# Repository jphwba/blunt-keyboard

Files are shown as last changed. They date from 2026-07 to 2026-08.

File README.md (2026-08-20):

# Blunt-Keyboard

This keyboard is a 75% keyboard which has a magnetically attatchable numpad to it. It uses a raspberry pi pico rp2040 as the microcontroller for the main keyboard while using a xiao seeed studio rp2040 as the microcontroller for the numpad. This would connect via two usb C cables into my pc. I made this because I really need a new keyboard since my current one cant even play games anymore due to some weird bug in the pcb where it just randomly spams keys, plus I've had it for almost 10 years.

## Assembly
On the main part of the keyboard, the pcb is mounted using five mounting holes on the pcb and five standoffs on the base where M2 heatset inserts will sit. On top of these standoffs will go the PCB where it will be screwed into the base. Then the top goes ontop of the pcb/base walls. This is connected via screws going from the bottom to the top
The numpad however is screwed in with the threads in the 3d print. This was not a great design choice at the time as I wasn't as experienced with how 3d printers work but I will take the gamble and if it doesn't work I am able to use tape. HOWEVER the pcb is screwed into the base using the same heatset inserts so the pcb will be secured. The key plate is attatched to the top cover with a joint (i forgot the name).
For the magnetic attatchements, two 7mm magnets go in two the 7mm wide holes on BOTH the numpad and the main keyboard and is attatched to each part with some basic super glue. With this the two devices can seamlessly attatch and detach. The two components also have seperate microcontrollers, meaning two different usb connections into my pc. I chose this over having the numpad atatch into the main keyboard for first simple firmware and schematic design but also because it means I have a portable numpad.

### Numpad Render
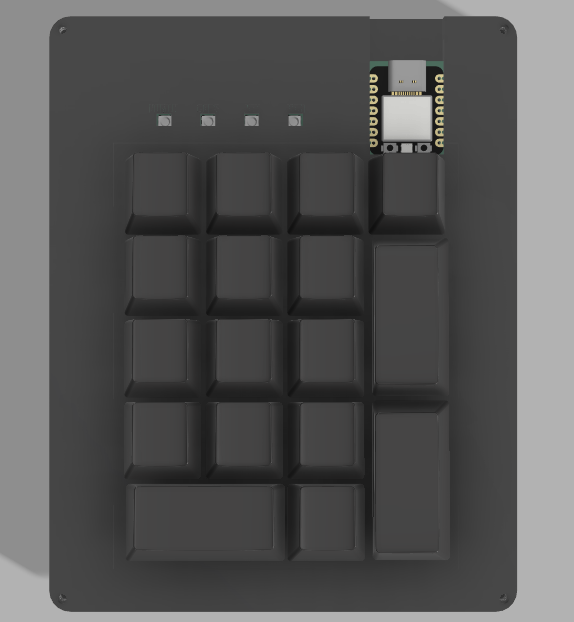
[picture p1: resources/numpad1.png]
NumPad1

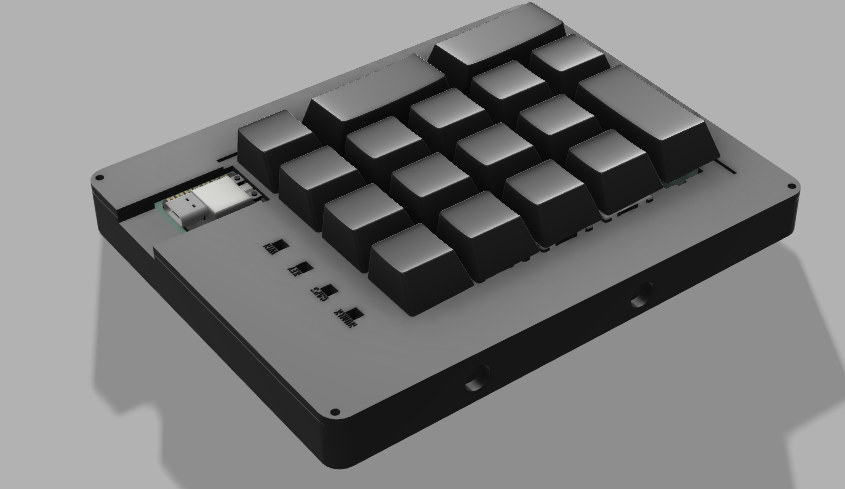
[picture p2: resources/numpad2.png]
Numpad2


### Main Keyboard Render
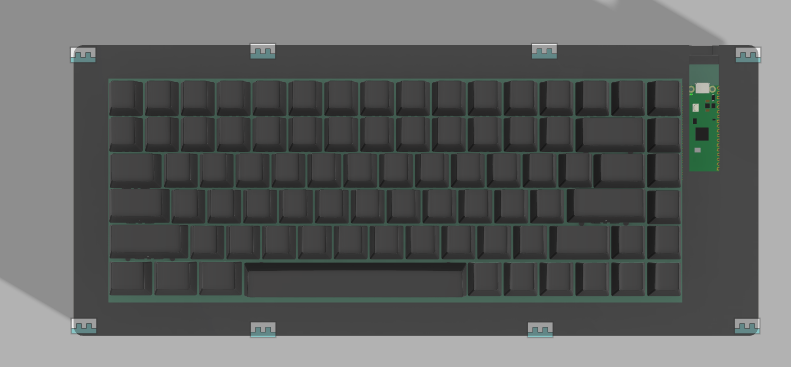
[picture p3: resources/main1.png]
Main1

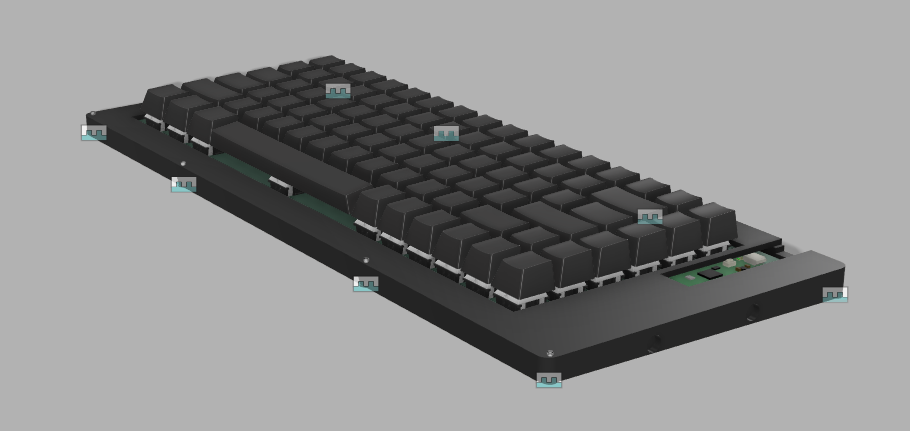
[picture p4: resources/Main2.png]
Main2


### Full Assembled Render
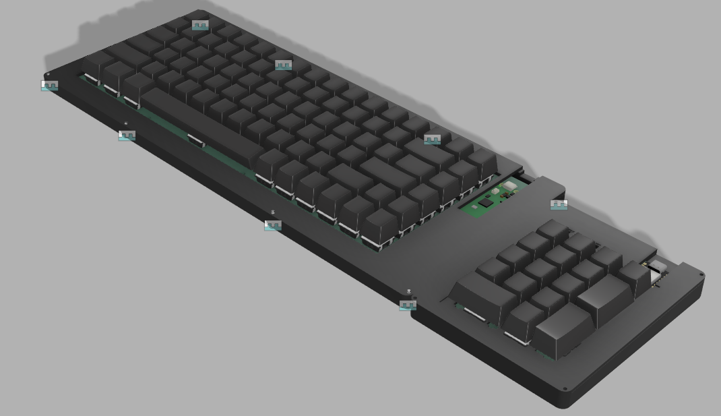
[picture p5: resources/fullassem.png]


### PCB Layout Pad
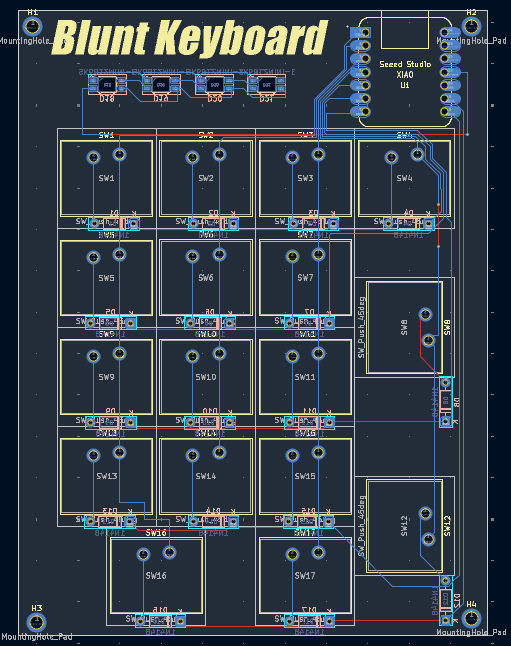
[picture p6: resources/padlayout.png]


### Pad Schematic
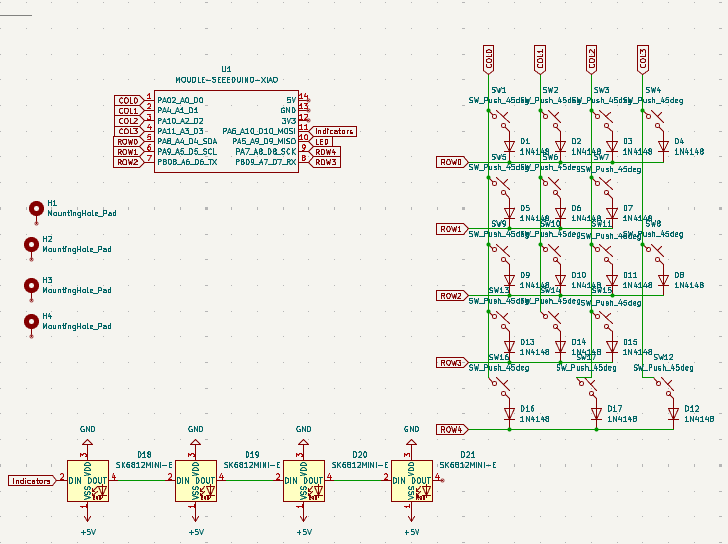
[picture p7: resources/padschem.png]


### Main PCB Layout
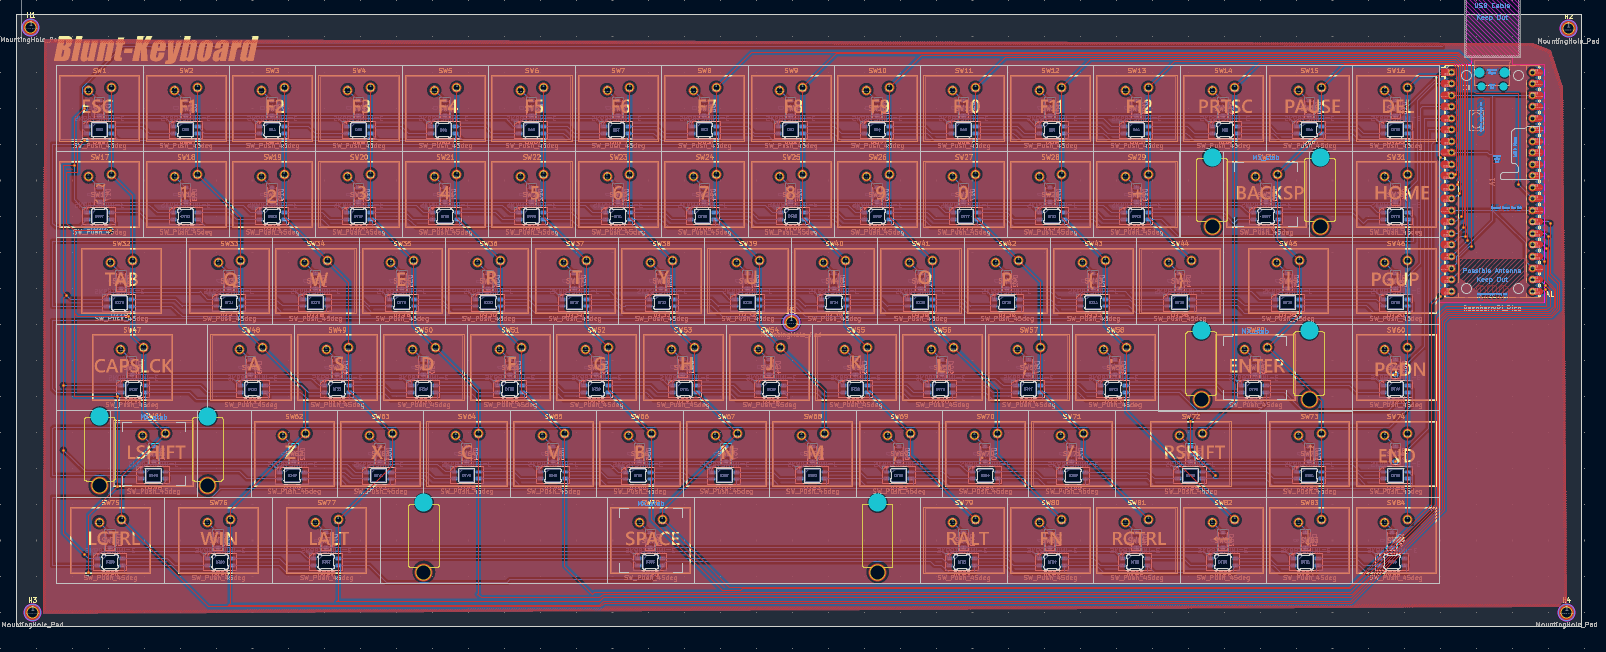
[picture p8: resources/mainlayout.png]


### Main Schematic
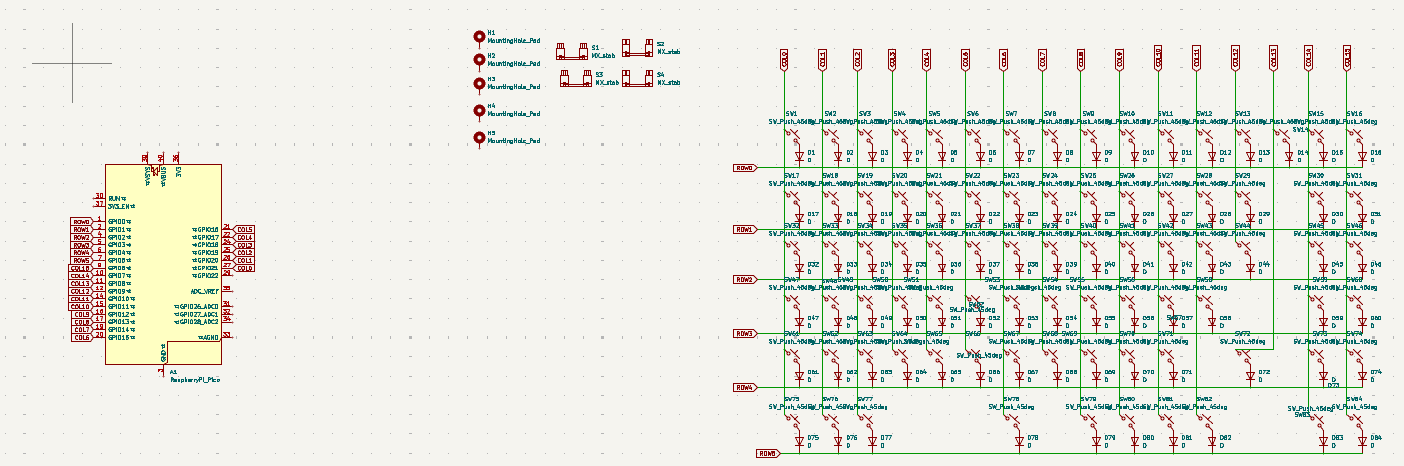
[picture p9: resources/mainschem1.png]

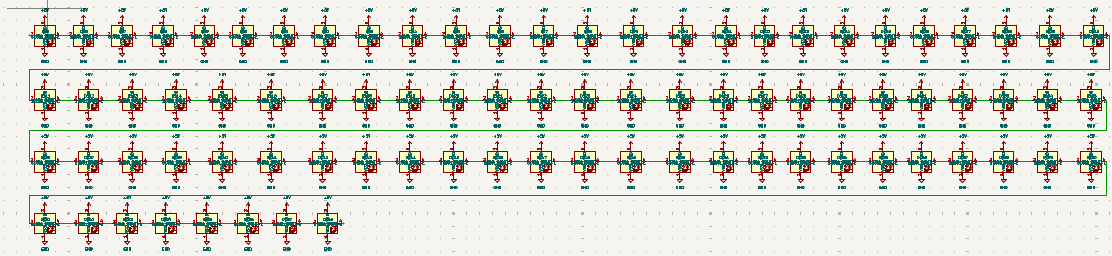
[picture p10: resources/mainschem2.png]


### Main PCB Order
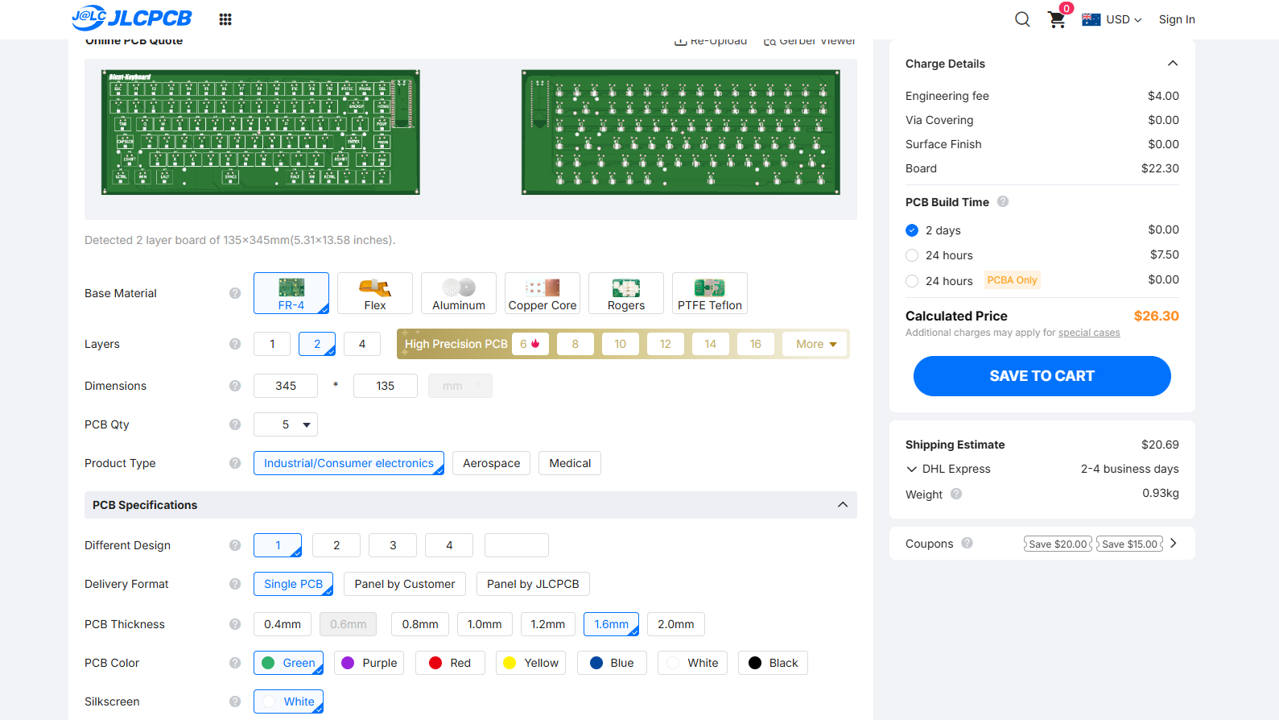
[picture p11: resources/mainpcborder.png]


### PAD PCB Order
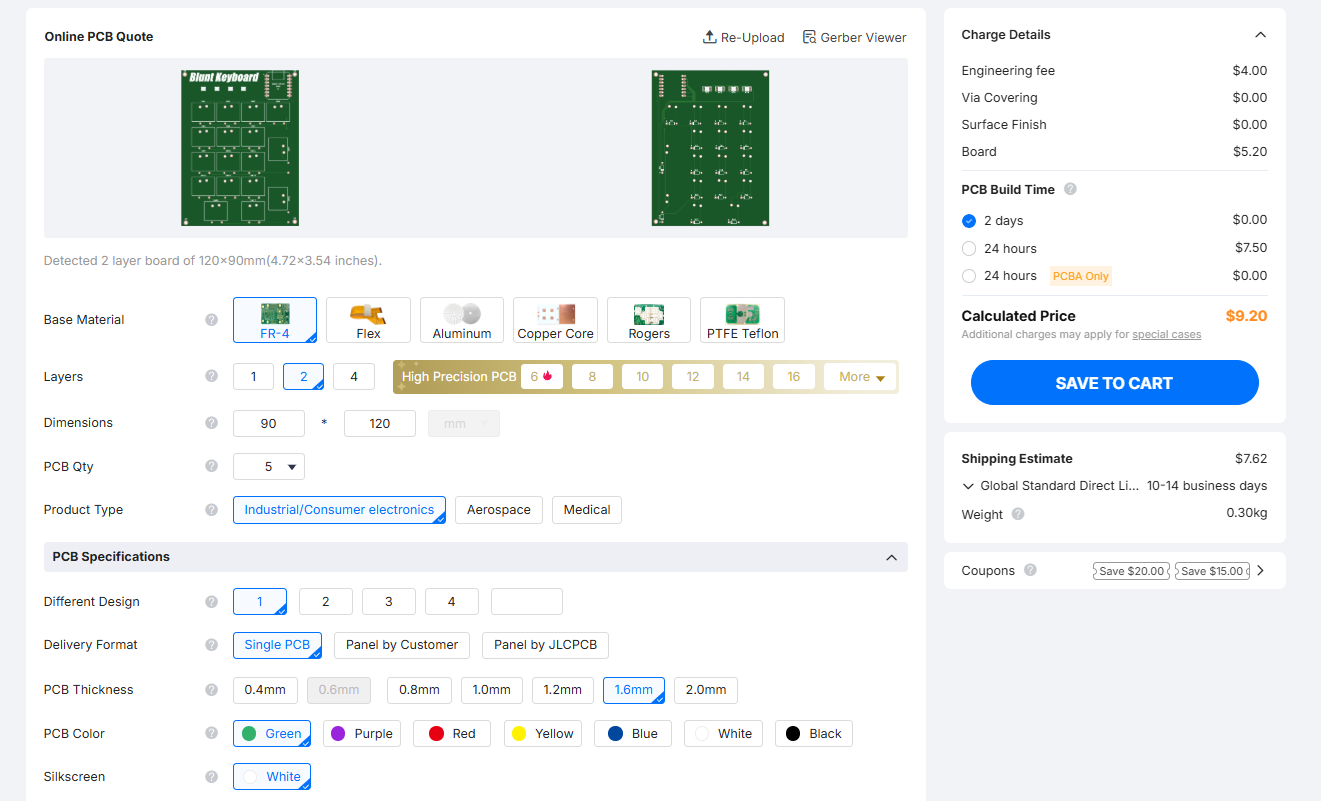
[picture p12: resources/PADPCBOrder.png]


### BOM
|Item |Qty|Price (AUD)|Site |
|---|---|---|---|
|DUROCK Plate Mount Stabilizers V3, Innovative Pre-clipped Stem for Minimum Wire Wobble 2U 6.25U 7U Plate Keyboard Stabilizers V3 (Color: V3 BS 4x2u 1x6.25u) |1  |$11.39 |https://www.aliexpress.com/item/1005006528731543.html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 |
|110Pcs Outemu Switches for Mechanical Keyboard 3Pin Clicky Linear Tactile Silent Switch RGB LED SMD Gaming Mechan with MX Switch (Color: 110p DustProof Brown) |1  |$43.46 |https://www.aliexpress.com/item/1005011976942889.html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 |
|100pcs/lot 1N4148W T4 BAV21W T3 SOD-123 1N4148WS BAV21WS SOD-323 1N4148WT SOD-523 1N4148 BAV21 BAV21W SMD Switching Diodes (Color: 1N4148W T4 SOD-123) |1  |$3.72 |https://www.aliexpress.com/item/1005007160563285.html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 |
|Original Raspberry Pi Pico Development Board,Pico or Pico H with Pin Header, support MciroPython/C++ |1  |$9.78 |https://www.aliexpress.com/item/1005008714908011.html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 |
|100PCS SK6812MINI-E SK6812 MINI-E RGB 3228 LED chip SMD |1  |$14.24 |https://www.aliexpress.com/item/1005005956813491.html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 |
|XVX 119 Keys Black Transparent PC Keycaps 60/68/75/87/98/100 Mechanical Keyboard Key Cap Crystal Clear Keycaps for Gaming/Office (Color: black) |1  |$30.84 |https://www.aliexpress.com/item/1005010587844811.html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 |
|50pcs 5-30mm Anti-slip Black Self Adhesive Round Silicone Rubber Feet Pad Laptops Keyboards Calculators Monitors Anti-skid Pads (Size: OD 15mm, Color: Thick 0.5mm) |1  |$3.25 |https://www.aliexpress.com/item/1005012365785428.html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 |
|10/15/20/40/50/100pcs M1 M1.2 M1.4 M2 M2.5 M3 M4 M5 M6 M8 Thread Knurled Brass Heat Insert Nut Copper Embedment Embed Parts Nuts (Size: M2x3.5mm (50pcs), Color: Length 3.5mm)|1  |$3.87 |https://www.aliexpress.com/item/1005007424930348.html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 |
|7x3 mm Powerful Magnets 7mmx3mm Small Round Magnet 7x3mm For Home Refrigerators, Offices DIY 7*3 mm (Color: 20PCS, Size: 7x3mm) |1  |$9.70 |https://www.aliexpress.com/item/1005009743408781.html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 |
|Pad Specific | | | |
|(50pcs) 1N4148W T4 4148WS 4148WT SOD-123/SOD-323/SOD-523 SMD Switching Diodes (Color: 1N4148W T4 SOD123) |1  |$0.88 |https://www.aliexpress.com/item/1005007406908801.html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 |
|10pcs/1pc RP2040 Seeed XIAO Raspberry Pi Development Board Module For Arduino/MicroPython/CircuitPython (Model Number: 1pc) |1  |$10.70 |https://www.aliexpress.com/item/1005008200917480.html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|
|Printing-Legion |1  |$30.00 | |
|Total | |$141.83 | |

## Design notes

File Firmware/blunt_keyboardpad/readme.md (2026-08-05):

# blunt_keyboardpad

blunt_keyboardpad

A short description of the keyboard/project

 Keyboard Maintainer: [Jenish](https://github.com/jphwba)
 Hardware Supported: The PCBs, controllers supported
 Hardware Availability: Links to where you can find this hardware

Make example for this keyboard (after setting up your build environment):

    make blunt_keyboardpad:default

Flashing example for this keyboard:

    make blunt_keyboardpad:default:flash

See the [build environment setup](https://docs.qmk.fm/#/getting_started_build_tools) and the [make instructions](https://docs.qmk.fm/#/getting_started_make_guide) for more information. Brand new to QMK? Start with our [Complete Newbs Guide](https://docs.qmk.fm/#/newbs).

## Bootloader

Enter the bootloader in 3 ways:

 Bootmagic reset: Hold down the key at (0,0) in the matrix (usually the top left key or Escape) and plug in the keyboard
 Physical reset button: Briefly press the button on the back of the PCB - some may have pads you must short instead
 Keycode in layout: Press the key mapped to `QK_BOOT` if it is available

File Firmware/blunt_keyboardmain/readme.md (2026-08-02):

# blunt_keyboardmain

* Keyboard Maintainer: [Jenish Pathak](https://github.com/jphwba)
* Hardware Supported: RP2040 (Raspberry Pi Pico)
* Hardware Availability: Custom PCB (Open Source)

Compile example for this keyboard:

    qmk compile -kb blunt_keyboardmain -km default

Flashing example for this keyboard:

    qmk flash -kb blunt_keyboardmain -km default

See the [build environment setup](https://docs.qmk.fm/#/getting_started_build_tools) and the [make instructions](https://docs.qmk.fm/#/getting_started_make_guide) for more information. Brand new to QMK? Start with our [Complete Newbs Guide](https://docs.qmk.fm/#/newbs).

## Bootloader

Enter the bootloader in 3 ways:

* **Bootmagic reset**: Hold down the key at (0,0) in the matrix (usually the top left key or Escape) and plug in the keyboard
* **Physical reset button**: Briefly press the button on the back of the PCB - some may have pads you must short instead
* **Keycode in layout**: Press the key mapped to `QK_BOOT` if it is available

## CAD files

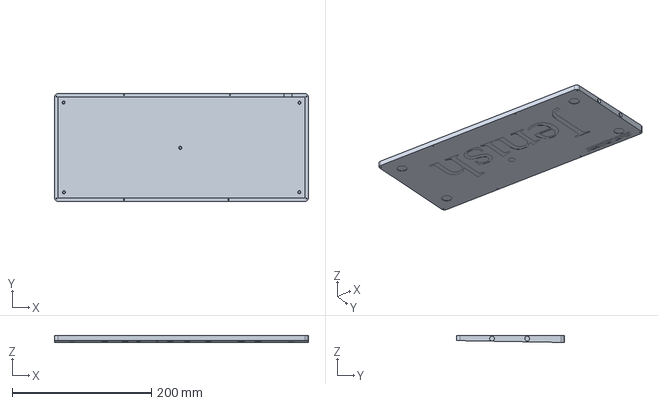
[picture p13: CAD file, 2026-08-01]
Production/Main/BaseMain.step
365.0 x 155.0 x 10.0 mm

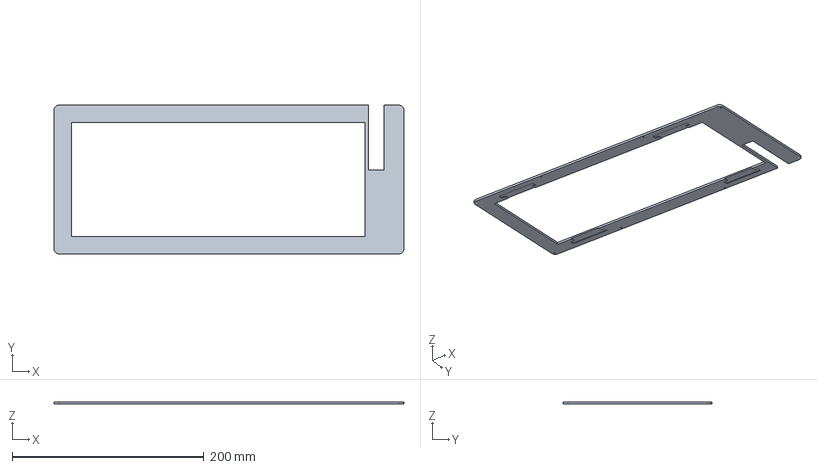
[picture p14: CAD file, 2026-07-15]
Production/Main/TopMain.step
365.0 x 155.0 x 2.50 mm

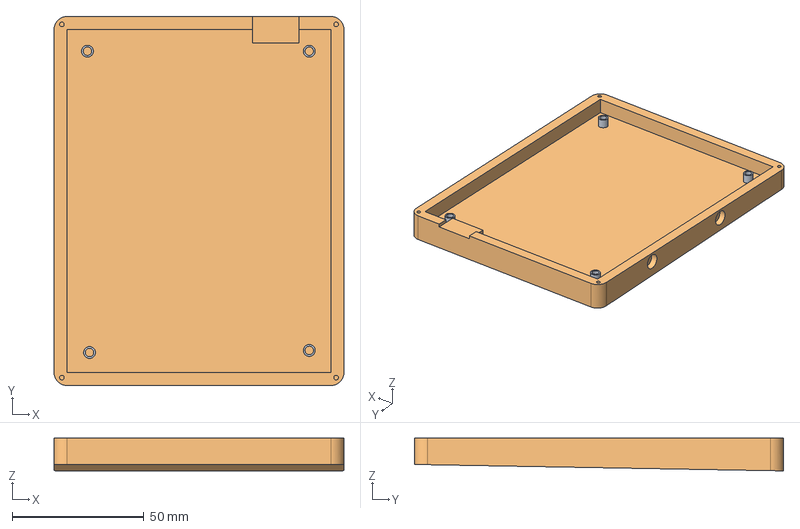
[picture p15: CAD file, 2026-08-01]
Production/Pad/BasePad.step
110.0 x 140.0 x 12.4 mm

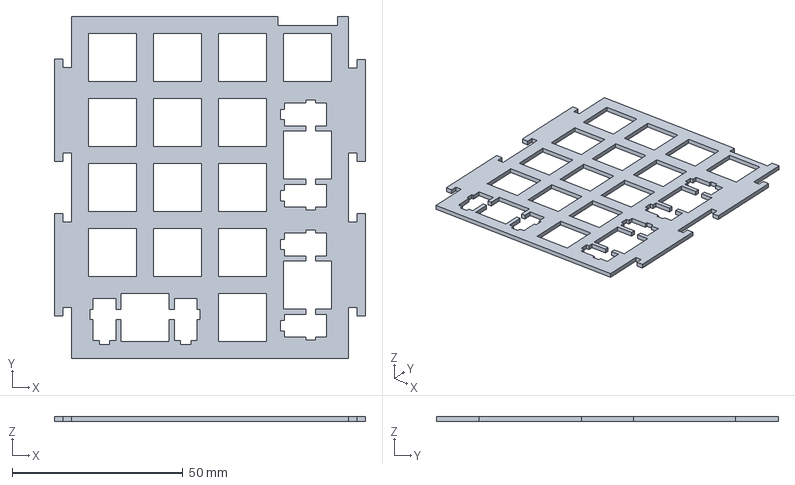
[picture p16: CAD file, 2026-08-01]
Production/Pad/MiddlePad.step
91.2 x 100.2 x 1.60 mm

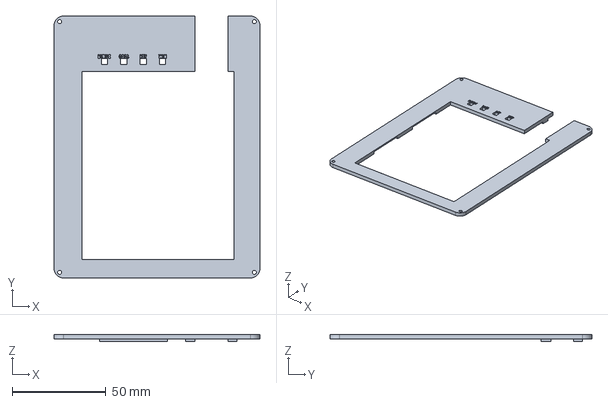
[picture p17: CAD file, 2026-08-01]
Production/Pad/TopPad.step
110.0 x 140.0 x 3.99 mm

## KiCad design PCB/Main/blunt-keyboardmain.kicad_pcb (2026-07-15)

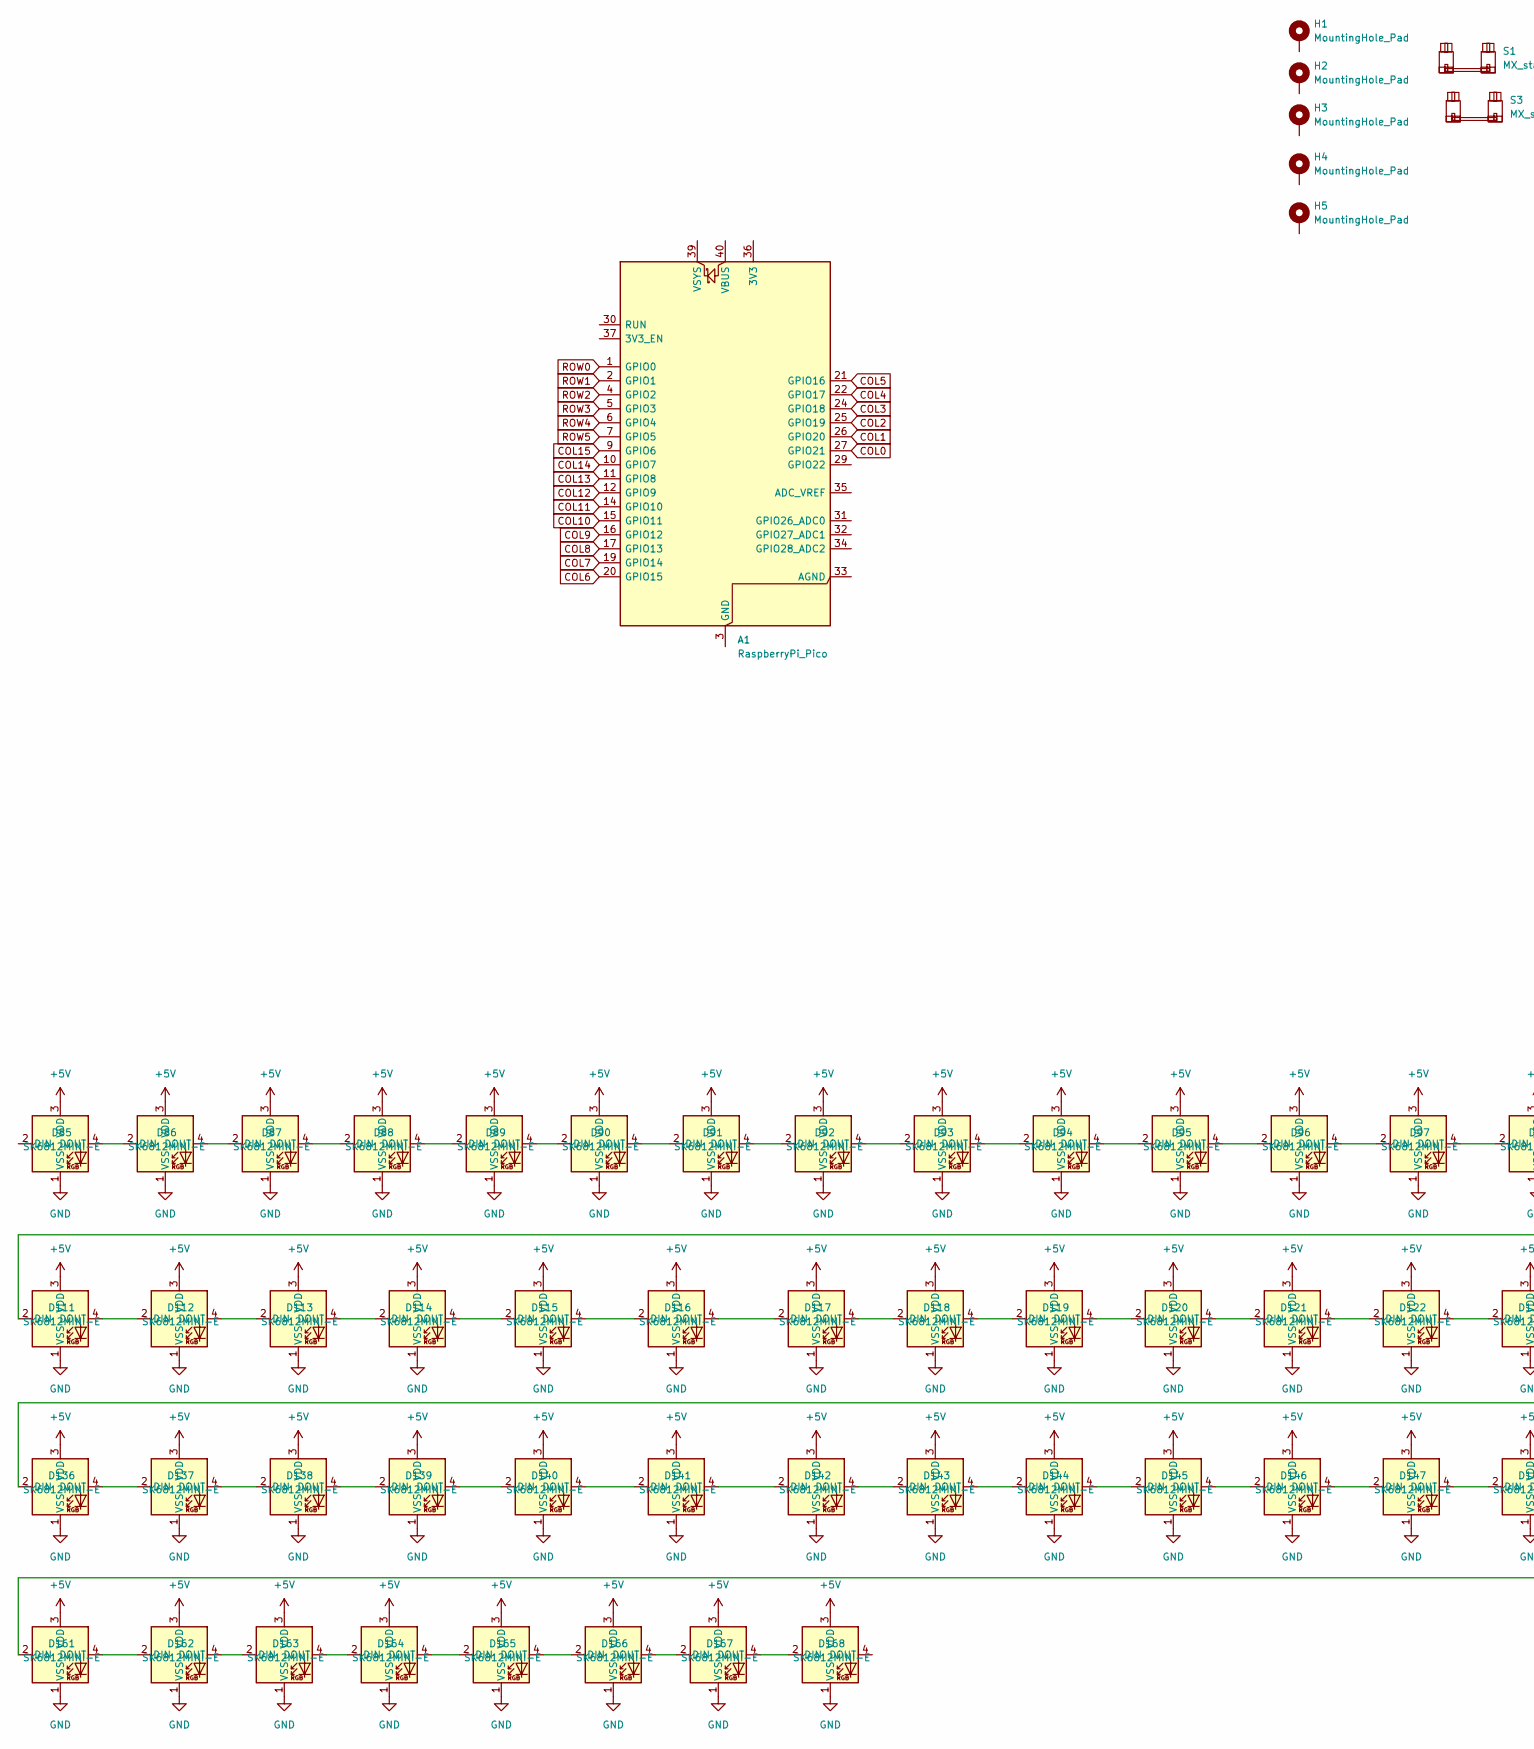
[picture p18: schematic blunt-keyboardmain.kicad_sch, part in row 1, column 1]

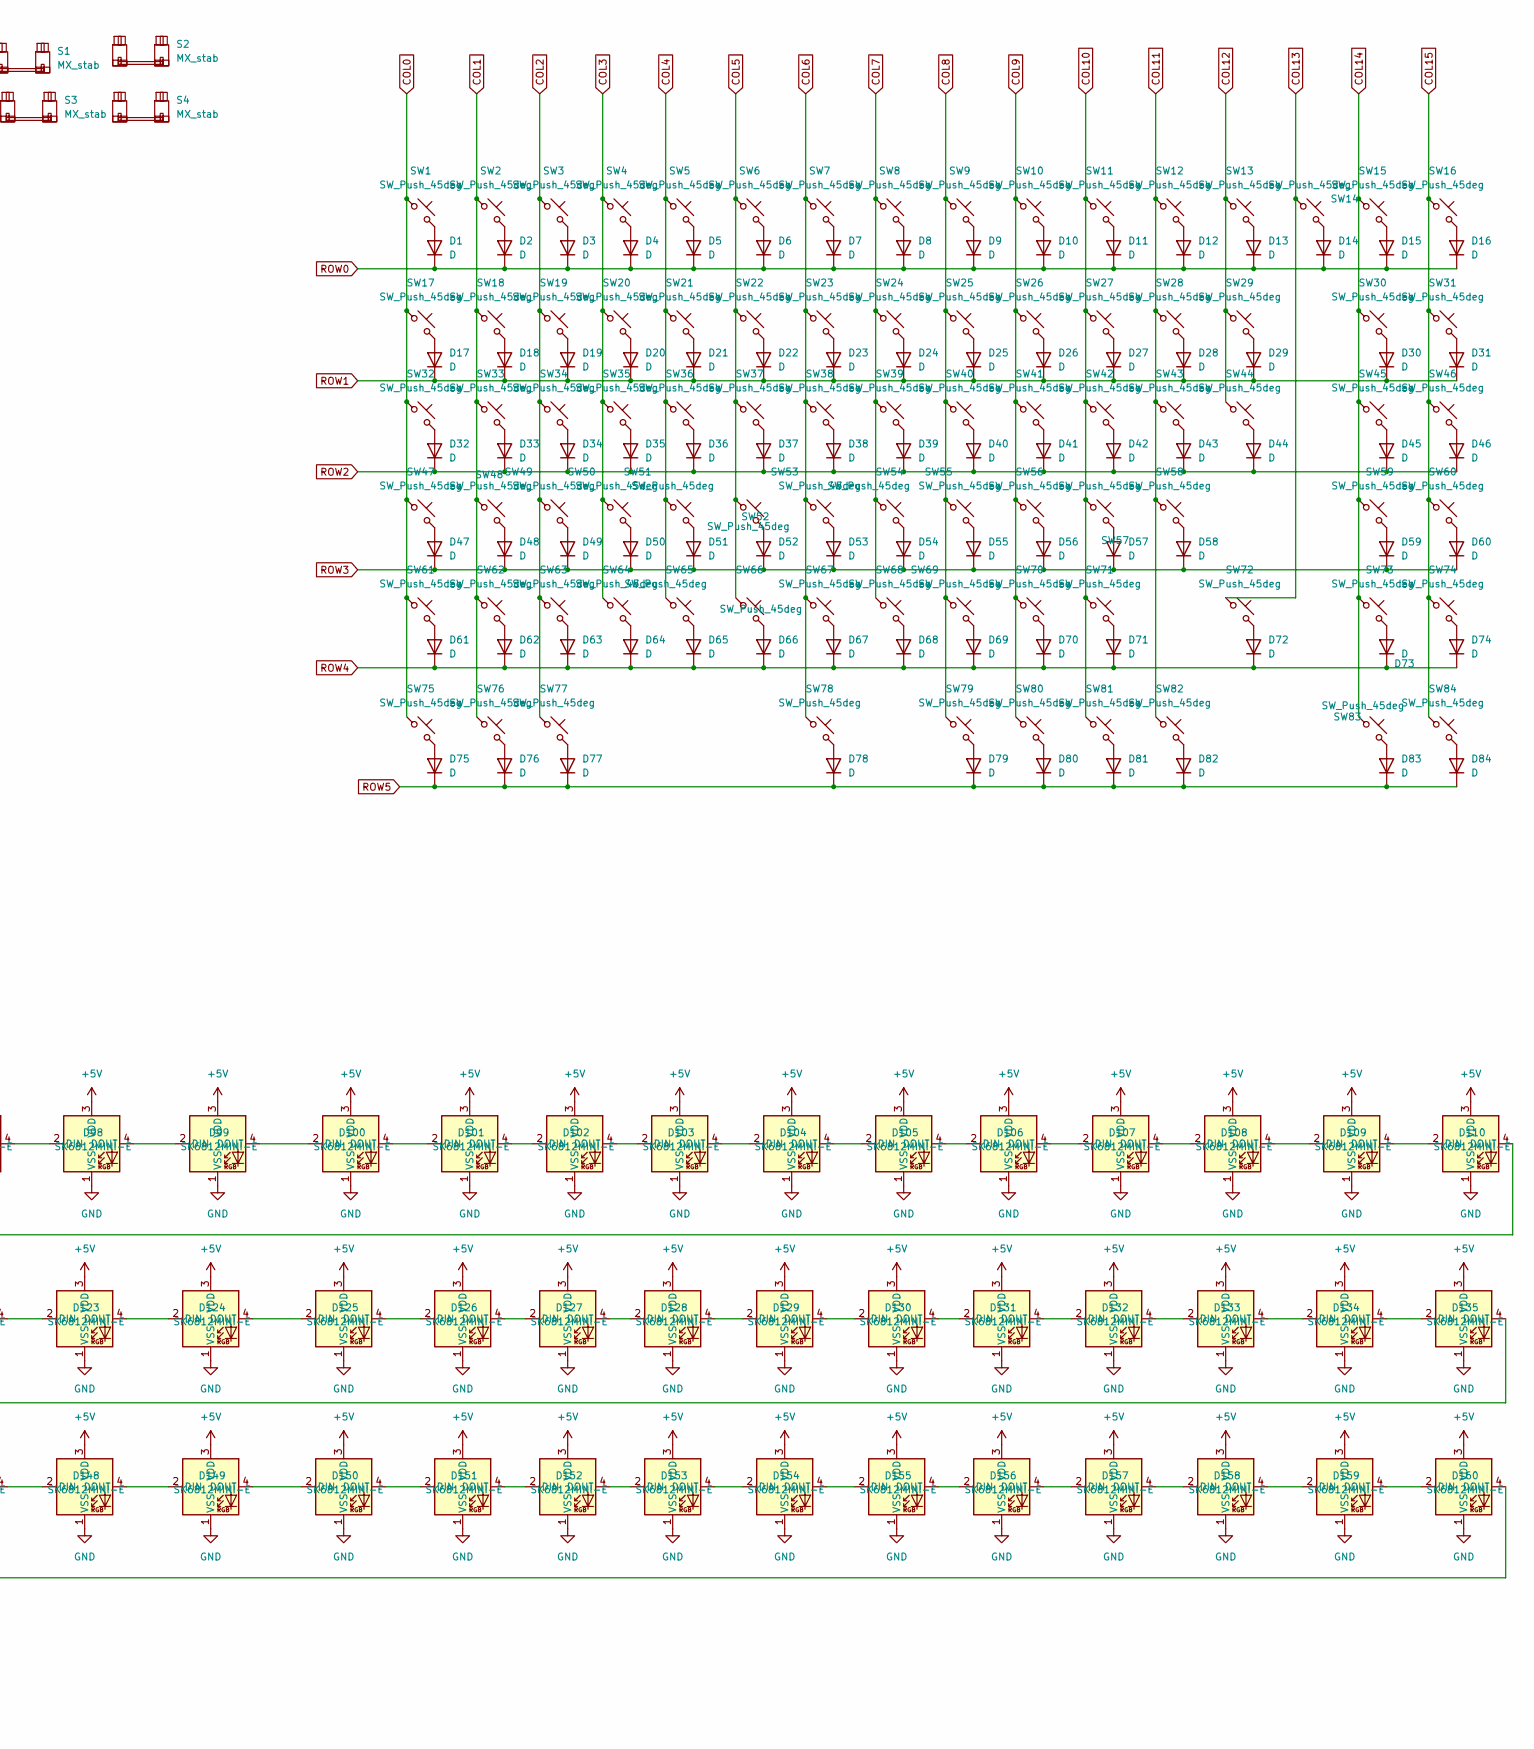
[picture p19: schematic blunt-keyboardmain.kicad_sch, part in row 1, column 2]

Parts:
A1: RaspberryPi_Pico; RaspberryPi_Pico_Common_Unspecified
D1, D2, D3, D4, D5, D6, D7, D8, D9, D10, D11, D12, D13, D14, D15, D16, D17, D18, D19, D20, D21, D22, D23, D24, D25, D26, D27, D28, D29, D30, D31, D32, D33, D34, D35, D36, D37, D38, D39, D40, D41, D42, D43, D44, D45, D46, D47, D48, D49, D50, D51, D52, D53, D54, D55, D56, D57, D58, D59, D60, D61, D62, D63, D64, D65, D66, D67, D68, D69, D70, D71, D72, D73, D74, D75, D76, D77, D78, D79, D80, D81, D82, D83, D84: D; D_SOD-123
D85, D86, D87, D88, D89, D90, D91, D92, D93, D94, D95, D96, D97, D98, D99, D100, D101, D102, D103, D104, D105, D106, D107, D108, D109, D110, D111, D112, D113, D114, D115, D116, D117, D118, D119, D120, D121, D122, D123, D124, D125, D126, D127, D128, D129, D130, D131, D132, D133, D134, D135, D136, D137, D138, D139, D140, D141, D142, D143, D144, D145, D146, D147, D148, D149, D150, D151, D152, D153, D154, D155, D156, D157, D158, D159, D160, D161, D162, D163, D164, D165, D166, D167, D168: SK6812MINI-E; LED_SK6812MINI-E_3.2x2.8mm_P1.5mm_ReverseMount
H1, H2, H3, H4, H5: MountingHole_Pad; MountingHole_2.2mm_M2_ISO7380_Pad
S1: MX_stab; STAB_MX_P_6.25u
S2, S4: MX_stab; STAB_MX_P_2.25u
S3: MX_stab; STAB_MX_P_2u
SW1, SW2, SW3, SW4, SW5, SW6, SW7, SW8, SW9, SW10, SW11, SW12, SW13, SW14, SW15, SW16, SW17, SW18, SW19, SW20, SW21, SW22, SW23, SW24, SW25, SW26, SW27, SW28, SW29, SW30, SW31, SW33, SW34, SW35, SW36, SW37, SW38, SW39, SW40, SW41, SW42, SW43, SW44, SW46, SW48, SW49, SW50, SW51, SW52, SW53, SW54, SW55, SW56, SW57, SW58, SW60, SW61, SW62, SW63, SW64, SW65, SW66, SW67, SW68, SW69, SW70, SW71, SW73, SW74, SW78, SW79, SW80, SW81, SW82, SW83, SW84: SW_Push_45deg; SW_Matias_1.00u
SW32, SW45: SW_Push_45deg; SW_Matias_1.50u
SW47, SW72: SW_Push_45deg; SW_Matias_1.75u
SW59: SW_Push_45deg; SW_Matias_2.25u
SW75, SW76, SW77: SW_Push_45deg; SW_Matias_1.25u

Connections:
+5V: D85.3 (VDD), D86.3 (VDD), D87.3 (VDD), D88.3 (VDD), D89.3 (VDD), D90.3 (VDD), D91.3 (VDD), D92.3 (VDD), D93.3 (VDD), D94.3 (VDD), D95.3 (VDD), D96.3 (VDD), D97.3 (VDD), D98.3 (VDD), D99.3 (VDD), D100.3 (VDD), D101.3 (VDD), D102.3 (VDD), D103.3 (VDD), D104.3 (VDD), D105.3 (VDD), D106.3 (VDD), D107.3 (VDD), D108.3 (VDD), D109.3 (VDD), D110.3 (VDD), D111.3 (VDD), D112.3 (VDD), D113.3 (VDD), D114.3 (VDD), D115.3 (VDD), D116.3 (VDD), D117.3 (VDD), D118.3 (VDD), D119.3 (VDD), D120.3 (VDD), D121.3 (VDD), D122.3 (VDD), D123.3 (VDD), D124.3 (VDD), D125.3 (VDD), D126.3 (VDD), D127.3 (VDD), D128.3 (VDD), D129.3 (VDD), D130.3 (VDD), D131.3 (VDD), D132.3 (VDD), D133.3 (VDD), D134.3 (VDD), D135.3 (VDD), D136.3 (VDD), D137.3 (VDD), D138.3 (VDD), D139.3 (VDD), D140.3 (VDD), D141.3 (VDD), D142.3 (VDD), D143.3 (VDD), D144.3 (VDD), D145.3 (VDD), D146.3 (VDD), D147.3 (VDD), D148.3 (VDD), D149.3 (VDD), D150.3 (VDD), D151.3 (VDD), D152.3 (VDD), D153.3 (VDD), D154.3 (VDD), D155.3 (VDD), D156.3 (VDD), D157.3 (VDD), D158.3 (VDD), D159.3 (VDD), D160.3 (VDD), D161.3 (VDD), D162.3 (VDD), D163.3 (VDD), D164.3 (VDD), D165.3 (VDD), D166.3 (VDD), D167.3 (VDD), D168.3 (VDD)
COL0: A1.27 (GPIO21), SW1.1, SW17.1, SW32.1, SW47.1, SW61.1, SW75.1
COL1: A1.26 (GPIO20), SW2.1, SW18.1, SW33.1, SW48.1, SW62.1, SW76.1
COL2: A1.25 (GPIO19), SW3.1, SW19.1, SW34.1, SW49.1, SW63.1, SW77.1
COL3: A1.24 (GPIO18), SW4.1, SW20.1, SW35.1, SW50.1, SW64.1
COL4: A1.22 (GPIO17), SW5.1, SW21.1, SW36.1, SW51.1, SW65.1
COL5: A1.21 (GPIO16), SW6.1, SW22.1, SW37.1, SW52.1, SW66.1
COL6: A1.20 (GPIO15), SW7.1, SW23.1, SW38.1, SW53.1, SW67.1, SW78.1
COL7: A1.19 (GPIO14), SW8.1, SW24.1, SW39.1, SW54.1, SW68.1
COL8: A1.17 (GPIO13), SW9.1, SW25.1, SW40.1, SW55.1, SW69.1, SW79.1
COL9: A1.16 (GPIO12), SW10.1, SW26.1, SW41.1, SW56.1, SW70.1, SW80.1
COL10: A1.15 (GPIO11), SW11.1, SW27.1, SW42.1, SW57.1, SW71.1, SW81.1
COL11: A1.14 (GPIO10), SW12.1, SW28.1, SW43.1, SW58.1, SW82.1
COL12: A1.12 (GPIO9), SW13.1, SW29.1, SW44.1
COL13: A1.11 (GPIO8), SW14.1, SW72.1
COL14: A1.10 (GPIO7), SW15.1, SW30.1, SW45.1, SW59.1, SW73.1, SW83.1
COL15: A1.9 (GPIO6), SW16.1, SW31.1, SW46.1, SW60.1, SW74.1, SW84.1
GND: D85.1 (VSS), D86.1 (VSS), D87.1 (VSS), D88.1 (VSS), D89.1 (VSS), D90.1 (VSS), D91.1 (VSS), D92.1 (VSS), D93.1 (VSS), D94.1 (VSS), D95.1 (VSS), D96.1 (VSS), D97.1 (VSS), D98.1 (VSS), D99.1 (VSS), D100.1 (VSS), D101.1 (VSS), D102.1 (VSS), D103.1 (VSS), D104.1 (VSS), D105.1 (VSS), D106.1 (VSS), D107.1 (VSS), D108.1 (VSS), D109.1 (VSS), D110.1 (VSS), D111.1 (VSS), D112.1 (VSS), D113.1 (VSS), D114.1 (VSS), D115.1 (VSS), D116.1 (VSS), D117.1 (VSS), D118.1 (VSS), D119.1 (VSS), D120.1 (VSS), D121.1 (VSS), D122.1 (VSS), D123.1 (VSS), D124.1 (VSS), D125.1 (VSS), D126.1 (VSS), D127.1 (VSS), D128.1 (VSS), D129.1 (VSS), D130.1 (VSS), D131.1 (VSS), D132.1 (VSS), D133.1 (VSS), D134.1 (VSS), D135.1 (VSS), D136.1 (VSS), D137.1 (VSS), D138.1 (VSS), D139.1 (VSS), D140.1 (VSS), D141.1 (VSS), D142.1 (VSS), D143.1 (VSS), D144.1 (VSS), D145.1 (VSS), D146.1 (VSS), D147.1 (VSS), D148.1 (VSS), D149.1 (VSS), D150.1 (VSS), D151.1 (VSS), D152.1 (VSS), D153.1 (VSS), D154.1 (VSS), D155.1 (VSS), D156.1 (VSS), D157.1 (VSS), D158.1 (VSS), D159.1 (VSS), D160.1 (VSS), D161.1 (VSS), D162.1 (VSS), D163.1 (VSS), D164.1 (VSS), D165.1 (VSS), D166.1 (VSS), D167.1 (VSS), D168.1 (VSS)
unnamed: A1.3 (GND), A1.8 (GND), A1.13 (GND), A1.18 (GND), A1.23 (GND), A1.28 (GND), A1.38 (GND)
unnamed: D1.2 (A), SW1.2
unnamed: D2.2 (A), SW2.2
unnamed: D3.2 (A), SW3.2
unnamed: D4.2 (A), SW4.2
unnamed: D5.2 (A), SW5.2
unnamed: D6.2 (A), SW6.2
unnamed: D7.2 (A), SW7.2
unnamed: D8.2 (A), SW8.2
unnamed: D9.2 (A), SW9.2
unnamed: D10.2 (A), SW10.2
unnamed: D11.2 (A), SW11.2
unnamed: D12.2 (A), SW12.2
unnamed: D13.2 (A), SW13.2
unnamed: D14.2 (A), SW14.2
unnamed: D15.2 (A), SW15.2
unnamed: D16.2 (A), SW16.2
unnamed: D17.2 (A), SW17.2
unnamed: D18.2 (A), SW18.2
unnamed: D19.2 (A), SW19.2
unnamed: D20.2 (A), SW20.2
unnamed: D21.2 (A), SW21.2
unnamed: D22.2 (A), SW22.2
unnamed: D23.2 (A), SW23.2
unnamed: D24.2 (A), SW24.2
unnamed: D25.2 (A), SW25.2
unnamed: D26.2 (A), SW26.2
unnamed: D27.2 (A), SW27.2
unnamed: D28.2 (A), SW28.2
unnamed: D29.2 (A), SW29.2
unnamed: D30.2 (A), SW30.2
unnamed: D31.2 (A), SW31.2
unnamed: D32.2 (A), SW32.2
unnamed: D33.2 (A), SW33.2
unnamed: D34.2 (A), SW34.2
unnamed: D35.2 (A), SW35.2
unnamed: D36.2 (A), SW36.2
unnamed: D37.2 (A), SW37.2
unnamed: D38.2 (A), SW38.2
unnamed: D39.2 (A), SW39.2
unnamed: D40.2 (A), SW40.2
unnamed: D41.2 (A), SW41.2
unnamed: D42.2 (A), SW42.2
unnamed: D43.2 (A), SW43.2
unnamed: D44.2 (A), SW44.2
unnamed: D45.2 (A), SW45.2
unnamed: D46.2 (A), SW46.2
unnamed: D47.2 (A), SW47.2
unnamed: D48.2 (A), SW48.2
unnamed: D49.2 (A), SW49.2
unnamed: D50.2 (A), SW50.2
unnamed: D51.2 (A), SW51.2
unnamed: D52.2 (A), SW52.2
unnamed: D53.2 (A), SW53.2
unnamed: D54.2 (A), SW54.2
unnamed: D55.2 (A), SW55.2
unnamed: D56.2 (A), SW56.2
unnamed: D57.2 (A), SW57.2
unnamed: D58.2 (A), SW58.2
unnamed: D59.2 (A), SW59.2
unnamed: D60.2 (A), SW60.2
unnamed: D61.2 (A), SW61.2
unnamed: D62.2 (A), SW62.2
unnamed: D63.2 (A), SW63.2
unnamed: D64.2 (A), SW64.2
unnamed: D65.2 (A), SW65.2
unnamed: D66.2 (A), SW66.2
unnamed: D67.2 (A), SW67.2
unnamed: D68.2 (A), SW68.2
unnamed: D69.2 (A), SW69.2
unnamed: D70.2 (A), SW70.2
unnamed: D71.2 (A), SW71.2
unnamed: D72.2 (A), SW72.2
unnamed: D73.2 (A), SW73.2
unnamed: D74.2 (A), SW74.2
unnamed: D75.2 (A), SW75.2
unnamed: D76.2 (A), SW76.2
unnamed: D77.2 (A), SW77.2
unnamed: D78.2 (A), SW78.2
unnamed: D79.2 (A), SW79.2
unnamed: D80.2 (A), SW80.2
unnamed: D81.2 (A), SW81.2
unnamed: D82.2 (A), SW82.2
unnamed: D83.2 (A), SW83.2
unnamed: D84.2 (A), SW84.2
unnamed: D85.4 (DOUT), D86.2 (DIN)
unnamed: D86.4 (DOUT), D87.2 (DIN)
unnamed: D87.4 (DOUT), D88.2 (DIN)
unnamed: D88.4 (DOUT), D89.2 (DIN)
unnamed: D89.4 (DOUT), D90.2 (DIN)
unnamed: D90.4 (DOUT), D91.2 (DIN)
unnamed: D91.4 (DOUT), D92.2 (DIN)
unnamed: D92.4 (DOUT), D93.2 (DIN)
unnamed: D93.4 (DOUT), D94.2 (DIN)
unnamed: D94.4 (DOUT), D95.2 (DIN)
unnamed: D95.4 (DOUT), D96.2 (DIN)
unnamed: D96.4 (DOUT), D97.2 (DIN)
unnamed: D97.4 (DOUT), D98.2 (DIN)
unnamed: D98.4 (DOUT), D99.2 (DIN)
unnamed: D99.4 (DOUT), D100.2 (DIN)
unnamed: D100.4 (DOUT), D101.2 (DIN)
unnamed: D101.4 (DOUT), D102.2 (DIN)
unnamed: D102.4 (DOUT), D103.2 (DIN)
unnamed: D103.4 (DOUT), D104.2 (DIN)
unnamed: D104.4 (DOUT), D105.2 (DIN)
unnamed: D105.4 (DOUT), D106.2 (DIN)
unnamed: D106.4 (DOUT), D107.2 (DIN)
unnamed: D107.4 (DOUT), D108.2 (DIN)
unnamed: D108.4 (DOUT), D109.2 (DIN)
unnamed: D109.4 (DOUT), D110.2 (DIN)
unnamed: D110.4 (DOUT), D111.2 (DIN)
unnamed: D111.4 (DOUT), D112.2 (DIN)
unnamed: D112.4 (DOUT), D113.2 (DIN)
unnamed: D113.4 (DOUT), D114.2 (DIN)
unnamed: D114.4 (DOUT), D115.2 (DIN)
unnamed: D115.4 (DOUT), D116.2 (DIN)
unnamed: D116.4 (DOUT), D117.2 (DIN)
unnamed: D117.4 (DOUT), D118.2 (DIN)
unnamed: D118.4 (DOUT), D119.2 (DIN)
unnamed: D119.4 (DOUT), D120.2 (DIN)
unnamed: D120.4 (DOUT), D121.2 (DIN)
unnamed: D121.4 (DOUT), D122.2 (DIN)
unnamed: D122.4 (DOUT), D123.2 (DIN)
unnamed: D123.4 (DOUT), D124.2 (DIN)
unnamed: D124.4 (DOUT), D125.2 (DIN)
unnamed: D125.4 (DOUT), D126.2 (DIN)
unnamed: D126.4 (DOUT), D127.2 (DIN)
unnamed: D127.4 (DOUT), D128.2 (DIN)
unnamed: D128.4 (DOUT), D129.2 (DIN)
unnamed: D129.4 (DOUT), D130.2 (DIN)
unnamed: D130.4 (DOUT), D131.2 (DIN)
unnamed: D131.4 (DOUT), D132.2 (DIN)
unnamed: D132.4 (DOUT), D133.2 (DIN)
unnamed: D133.4 (DOUT), D134.2 (DIN)
unnamed: D134.4 (DOUT), D135.2 (DIN)
unnamed: D135.4 (DOUT), D136.2 (DIN)
unnamed: D136.4 (DOUT), D137.2 (DIN)
unnamed: D137.4 (DOUT), D138.2 (DIN)
unnamed: D138.4 (DOUT), D139.2 (DIN)
unnamed: D139.4 (DOUT), D140.2 (DIN)
unnamed: D140.4 (DOUT), D141.2 (DIN)
unnamed: D141.4 (DOUT), D142.2 (DIN)
unnamed: D142.4 (DOUT), D143.2 (DIN)
unnamed: D143.4 (DOUT), D144.2 (DIN)
unnamed: D144.4 (DOUT), D145.2 (DIN)
unnamed: D145.4 (DOUT), D146.2 (DIN)
unnamed: D146.4 (DOUT), D147.2 (DIN)
unnamed: D147.4 (DOUT), D148.2 (DIN)
unnamed: D148.4 (DOUT), D149.2 (DIN)
unnamed: D149.4 (DOUT), D150.2 (DIN)
unnamed: D150.4 (DOUT), D151.2 (DIN)
unnamed: D151.4 (DOUT), D152.2 (DIN)
unnamed: D152.4 (DOUT), D153.2 (DIN)
unnamed: D153.4 (DOUT), D154.2 (DIN)
unnamed: D154.4 (DOUT), D155.2 (DIN)
unnamed: D155.4 (DOUT), D156.2 (DIN)
unnamed: D156.4 (DOUT), D157.2 (DIN)
unnamed: D157.4 (DOUT), D158.2 (DIN)
unnamed: D158.4 (DOUT), D159.2 (DIN)
unnamed: D159.4 (DOUT), D160.2 (DIN)
unnamed: D160.4 (DOUT), D161.2 (DIN)
unnamed: D161.4 (DOUT), D162.2 (DIN)
unnamed: D162.4 (DOUT), D163.2 (DIN)
unnamed: D163.4 (DOUT), D164.2 (DIN)
unnamed: D164.4 (DOUT), D165.2 (DIN)
unnamed: D165.4 (DOUT), D166.2 (DIN)
unnamed: D166.4 (DOUT), D167.2 (DIN)
unnamed: D167.4 (DOUT), D168.2 (DIN)
ROW0: A1.1 (GPIO0), D1.1 (K), D2.1 (K), D3.1 (K), D4.1 (K), D5.1 (K), D6.1 (K), D7.1 (K), D8.1 (K), D9.1 (K), D10.1 (K), D11.1 (K), D12.1 (K), D13.1 (K), D14.1 (K), D15.1 (K), D16.1 (K)
ROW1: A1.2 (GPIO1), D17.1 (K), D18.1 (K), D19.1 (K), D20.1 (K), D21.1 (K), D22.1 (K), D23.1 (K), D24.1 (K), D25.1 (K), D26.1 (K), D27.1 (K), D28.1 (K), D29.1 (K), D30.1 (K), D31.1 (K)
ROW2: A1.4 (GPIO2), D32.1 (K), D33.1 (K), D34.1 (K), D35.1 (K), D36.1 (K), D37.1 (K), D38.1 (K), D39.1 (K), D40.1 (K), D41.1 (K), D42.1 (K), D43.1 (K), D44.1 (K), D45.1 (K), D46.1 (K)
ROW3: A1.5 (GPIO3), D47.1 (K), D48.1 (K), D49.1 (K), D50.1 (K), D51.1 (K), D52.1 (K), D53.1 (K), D54.1 (K), D55.1 (K), D56.1 (K), D57.1 (K), D58.1 (K), D59.1 (K), D60.1 (K)
ROW4: A1.6 (GPIO4), D61.1 (K), D62.1 (K), D63.1 (K), D64.1 (K), D65.1 (K), D66.1 (K), D67.1 (K), D68.1 (K), D69.1 (K), D70.1 (K), D71.1 (K), D72.1 (K), D73.1 (K), D74.1 (K)
ROW5: A1.7 (GPIO5), D75.1 (K), D76.1 (K), D77.1 (K), D78.1 (K), D79.1 (K), D80.1 (K), D81.1 (K), D82.1 (K), D83.1 (K), D84.1 (K)

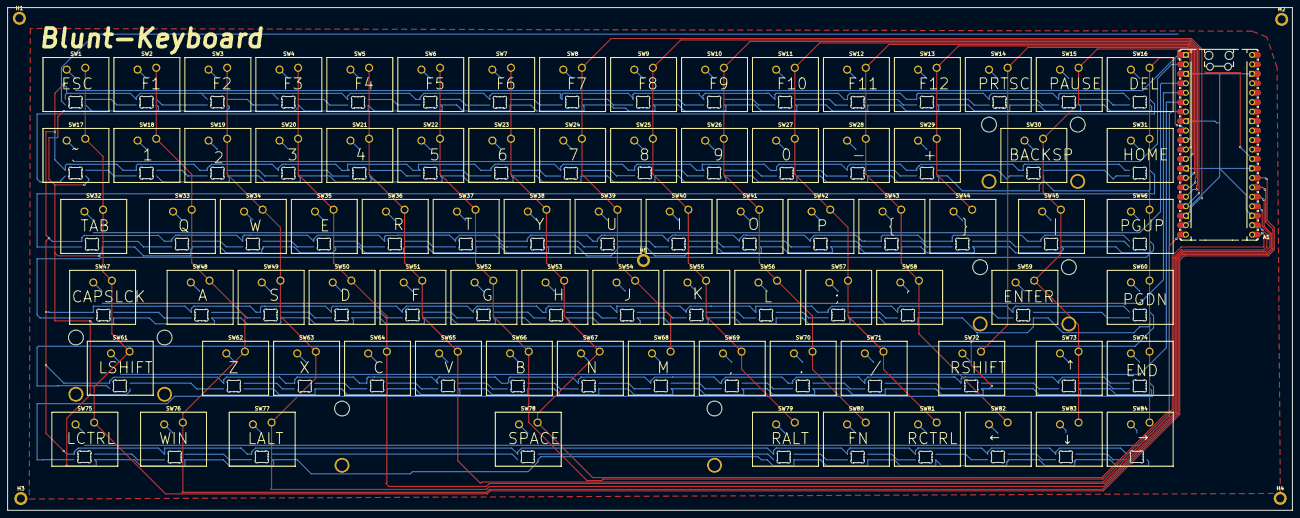
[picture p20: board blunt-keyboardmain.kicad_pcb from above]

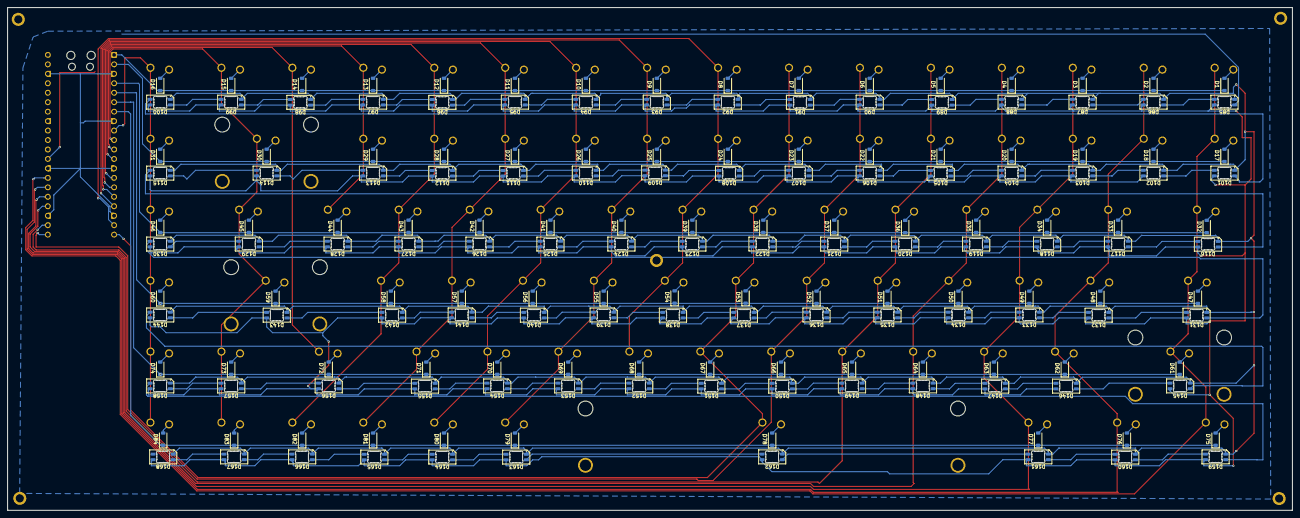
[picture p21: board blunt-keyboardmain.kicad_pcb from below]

Board: 2 copper layers, 345.0 x 135.0 mm, 262 parts (168 on the bottom side), 192 nets.

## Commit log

2026-07-15 Upload CAD files
    [BaseMain.step, BasePad.step, MiddlePad.step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]
2026-07-15 Add Gerbers and pcb
    [BaseMain.step, BasePad.step, MiddlePad.step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]
2026-08-01 Add BOM and README also updated CAD
    [BaseMain.step, BasePad.step, BluntKeyboard-BOM.csv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]
2026-08-01 ADD PCB Order quote to readme
2026-08-05 Update BOM
    [BluntKeyboard-BOM.csv]
2026-08-20 update BOM with printing-legion
    [BOM.csv]
